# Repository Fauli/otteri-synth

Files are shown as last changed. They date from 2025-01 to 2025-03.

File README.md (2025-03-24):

# Otteri-synth

<p align="center">
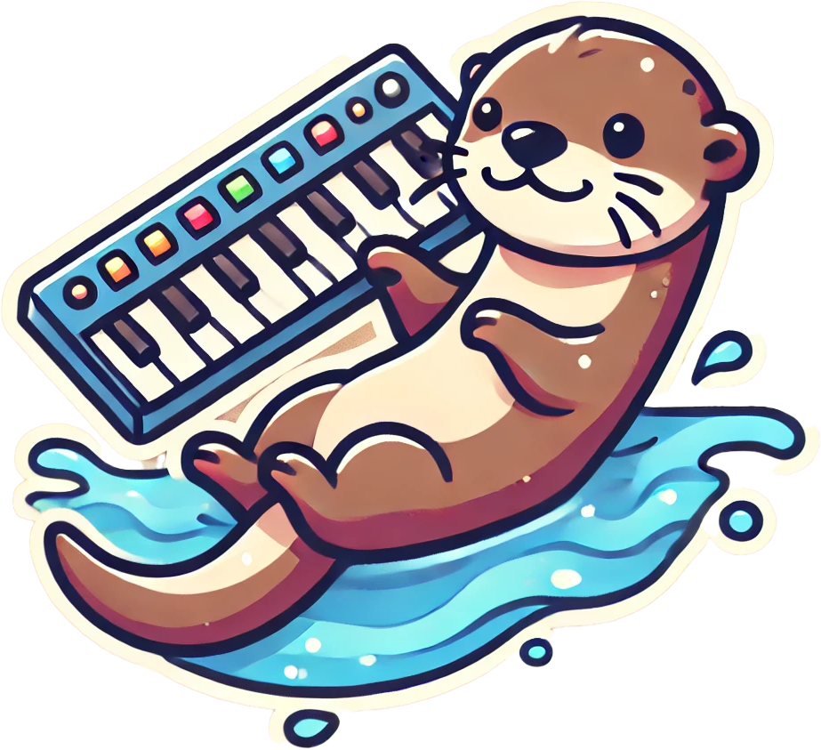
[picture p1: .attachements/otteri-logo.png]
Otteri DALL-E Image
    
    <br/>
    Cause otters like to play!
</p>

## Table of Contents

- [Otteri-synth](#otteri-synth)
  - [Table of Contents](#table-of-contents)
- [Introduction](#introduction)
- [Design](#design)
- [Hardware](#hardware)
  - [Parts List](#parts-list)
  - [Case](#case)
  - [Microcontroller](#microcontroller)
  - [Amplifier \& speakers](#amplifier--speakers)
  - [Power management](#power-management)
  - [Wiring diagram](#wiring-diagram)
  - [Final print config](#final-print-config)
  - [Putting it all together](#putting-it-all-together)
    - [KiCad](#kicad)
  - [Importing Teensy into KiCad](#importing-teensy-into-kicad)
  - [Schematics and PCB design](#schematics-and-pcb-design)
  - [Implementation using Perf Board](#implementation-using-perf-board)
  - [Ground loop](#ground-loop)
  - [Finished product](#finished-product)
    - [Final Project Files](#final-project-files)
- [Software](#software)
- [Demo](#demo)
- [Personal conclusion \& learnings](#personal-conclusion--learnings)

# Introduction
For fun I wanted to create a synthesizer that looks like an otter. It should be my daughters first synth :)

In these modern times I wanted to leverage what new tools have been available to design this project. In my mind I had a clear vision how the synth should look and play. I never did such a project before, so it was also a learning experience for me.

# Design
As the base I generated an image using [DALL-E](https://openai.com/index/dall-e-2/) and fed it into [TRELLIS](https://huggingface.co/JeffreyXiang/TRELLIS-image-large).

The prompt was:
```bash
Create a prototype of a synthesizer case.
White background, it is important that there is no background at all in the image. Should be childrens style, cool design and possible to 3d print on a 3d printer. I want to actually implement the case and use it for a synth project.
The synth should somewhat look like an otter.

# after some back and forth with some prototypes that had too many hands :P
There are too many hands, start over with an otter design, surprise me with a new and cool idea
```

In the end I was able to create an image in DALL-E that exactly matched what I had in mind.

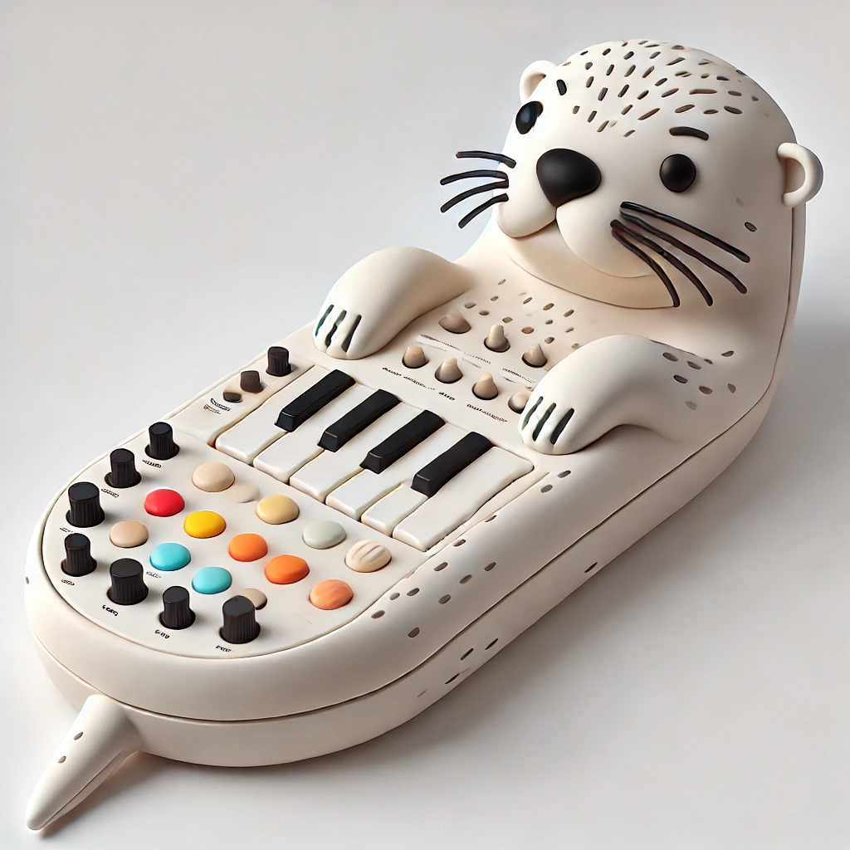
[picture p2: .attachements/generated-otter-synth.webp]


TRELLIS created an amazing mesh out of it that I could directly use as a starting point in [Blender](https://www.blender.org/).
You can find and download the mesh [here](.attachements/otteri-synth-generated.glb).

I then adapted the generated mesh to my liking and needs.

# Hardware

Because I have a 3d printer, the case and inner works was specially made for this synth.

## Parts List

Here is a quick overview of the used parts. A detailed description can be found below.

| Part | Amount | Description |
| --- | --- | --- |
| 3D Printed Case | 1 | Custom case to house all components |
| Teensy 3.2 | 1 | Microcontroller for handling audio processing |
| Teensy Audio Shield | 1 | Audio processing shield for Teensy |
| Adafruit MAX7944 | 1 | Amplifier for driving the speakers |
| 4Ohm 5W 40mm Speakers | 2 | Small speakers for audio output |
| Arcade Buttons | 10 | Durable buttons for user interaction |
| DC-015 circular power plug | 1 | Power plug for the synth |
| M5Stack Buck Converter 5 V | 1 | 12V to 5V converter for Teensy power |
| Ground Loop isolator | 1 | Prevent hum sound in speaker |
| Various Wires | - | Wiring for connecting all components |

## Case

The initial prototype was small, but after confirming its success, I scaled up the design to accommodate robust electronics suitable for a child's enthusiastic use. 

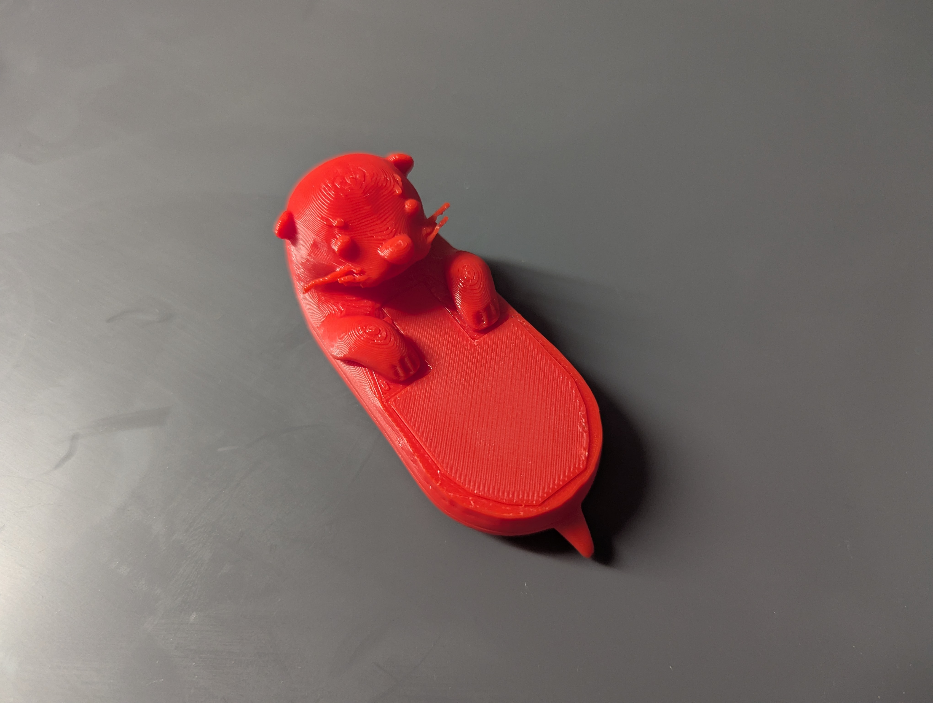
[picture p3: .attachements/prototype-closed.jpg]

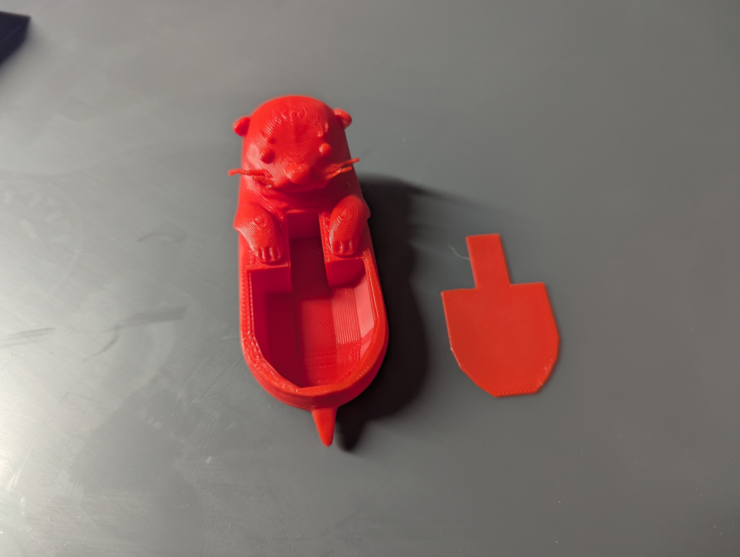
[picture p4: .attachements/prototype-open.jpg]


I opted for durable arcade buttons to withstand frequent interaction.

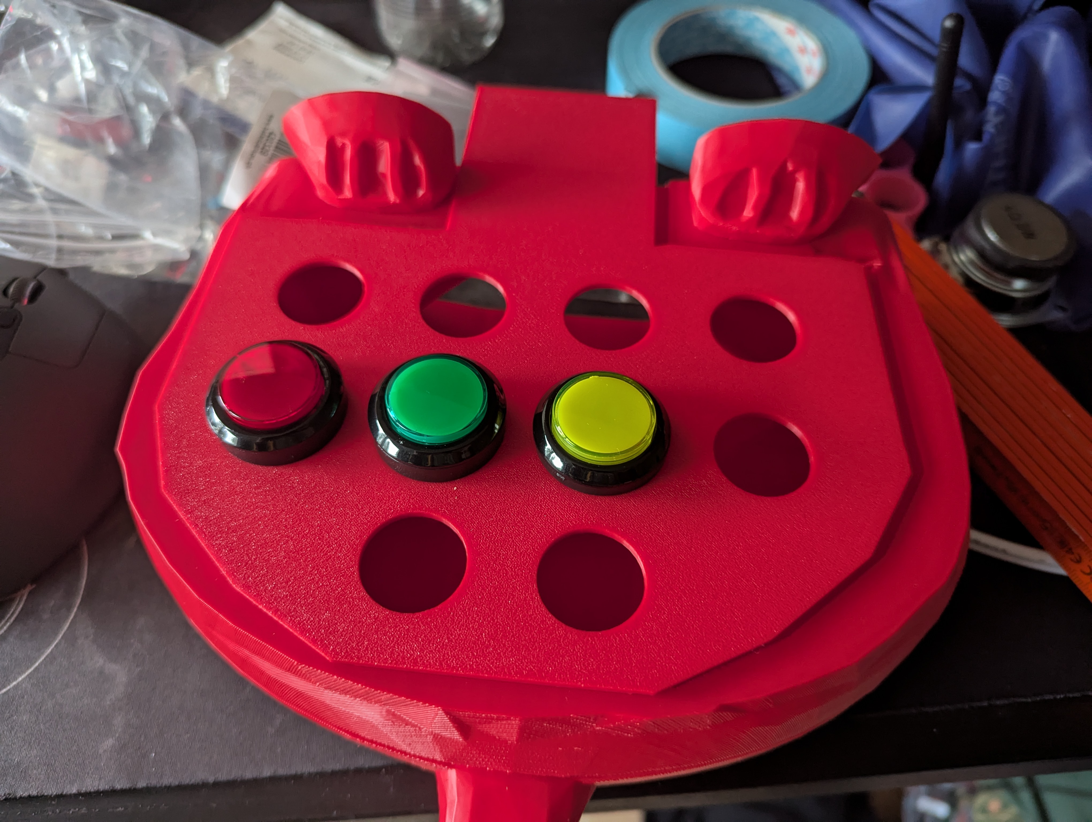
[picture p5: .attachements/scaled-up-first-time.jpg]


## Microcontroller

The core of the Otteri-synth is powered by a [Teensy 3.2](https://www.pjrc.com/store/teensy32.html) with the [Teensy Audio Shield](https://www.pjrc.com/store/teensy3_audio.html) as I still had them laying around at home.

The Teensy is excellent for synthesizer projects due to its high-performance ARM Cortex-M4 processor and real-time audio processing capabilities,

I'm a big fan of the teensy boards!

## Amplifier & speakers

Another component I still had laying around at home was an [Adafruit MAX7944](https://www.adafruit.com/product/1752) amplifier. For the speakers size, this will be more then enough.

As speakers I'm using 2 4Ohm 3W 40mm. They might be a little small, but should do the job.

## Power management

Teensy supports 5V power input, the amplifier needs 12V. In order to now have 2 inputs for power, I'm using a [Buck Converter - U125 - ME3116AM6G Step-Down Voltage Converter Unit, 5V, 1A](https://www.distrelec.ch/en/me3116am6g-step-down-voltage-converter-unit-5v-1a-m5stack-u125/p/30230761) to have the 12V shared input stepped down to 5V for the teensy:

```

          +---------------+
          |  12V Supply   |
          +---------------+
                |   |
                |   | 
         +------+   +------+  
         |                 |
  [Buck Converter]         |  
         |                 |
      5V Output        12V Output
         |                 |
   +-----+----+      +-----+-----+
   |  Teensy  |      | Amplifier |
   |   3.2    |      | (MAX9744) |
   +----------+      +-----------+
         |                 |
         +-- Common Ground --------+
```

To be able to re-use standard 12V power adapters, I prepared a hole at the back of the synth and added a circular power plug.

## Wiring diagram

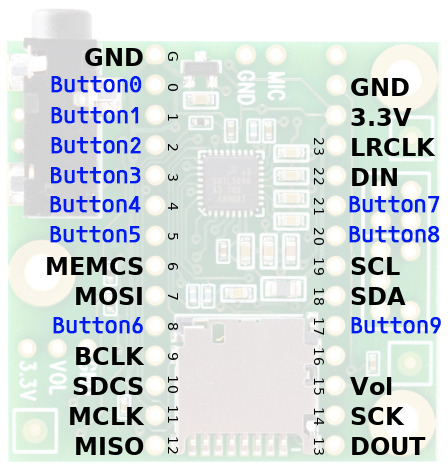
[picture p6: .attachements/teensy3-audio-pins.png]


| Button | Pin | Description |
| --- | --- | --- |
| Button 0 | 0 | Play note C |
| Button 1 | 1 | Play note D |
| Button 2 | 2 | Play note E |
| Button 3 | 3 | Play note F |
| Button 4 | 4 | Play note G |
| Button 5 | 5 | Play note A |
| Button 6 | 8 | Play note B |
| Button 7 | 21  | Play note C |
| Button 8 | 20  | Change preset (instrument) + volume |
| Button 9 | 17  | Change octave + volume |

*Additional note:* I added the functionality to change the volume by holding down Button 8 and Button 9 simultaneously and then changing the volume down or up with Button 0 and Button 1.

## Final print config

The first half I printed had way too small dowels. So they ended up breaking when being inserted into the body. 

So in try 2, I cut the Otter in Bambu Studio, using hexagons dowels with length 2cm and 1.5cm diameter as connectors. Initially I had a small gap between the two pieces. So I manually reduced the length of the dowels and re-printed just these.

**TODO: Add 3mf file of project...**

## Putting it all together

A first circuit prototype was made with a breadboard and some initial buttons I had still at home. The order for the remaining buttons was on it's way.

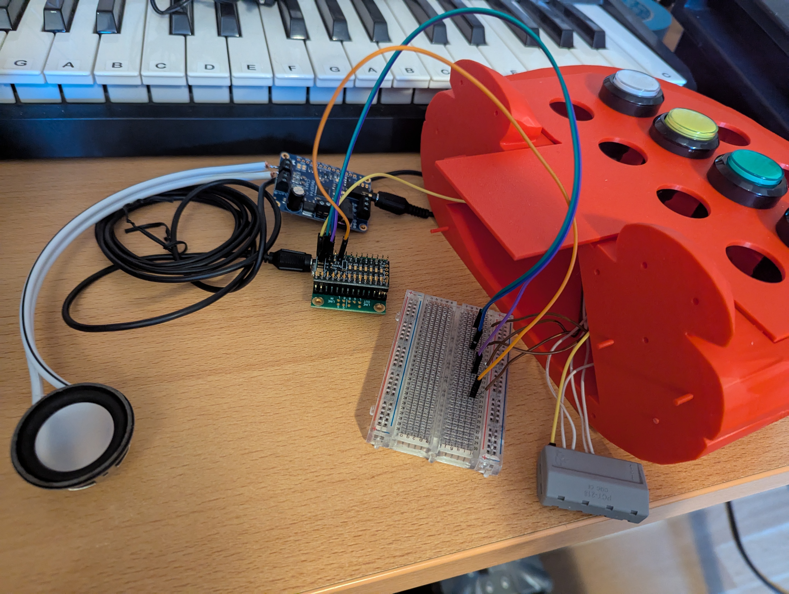
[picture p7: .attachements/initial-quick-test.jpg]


To fix the plate with the buttons to the body of the synth, I got melt threads in M3 size, like these:
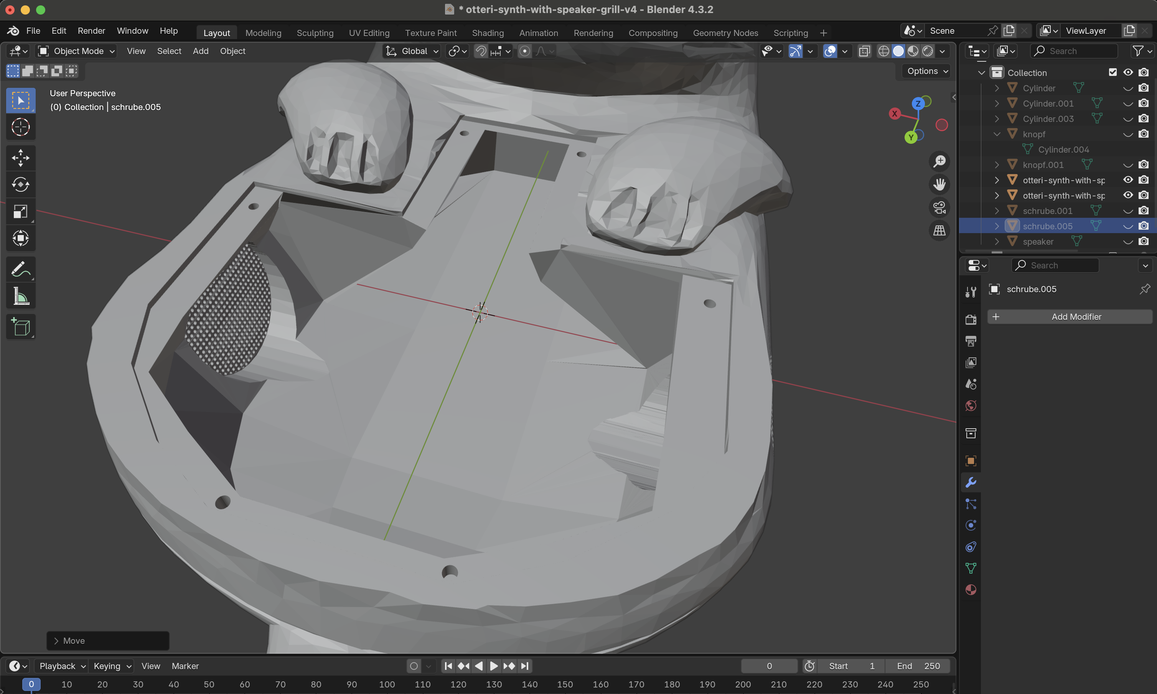
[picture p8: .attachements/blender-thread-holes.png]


In Blender I prepared the matching 4mm holes to fix the threads in.
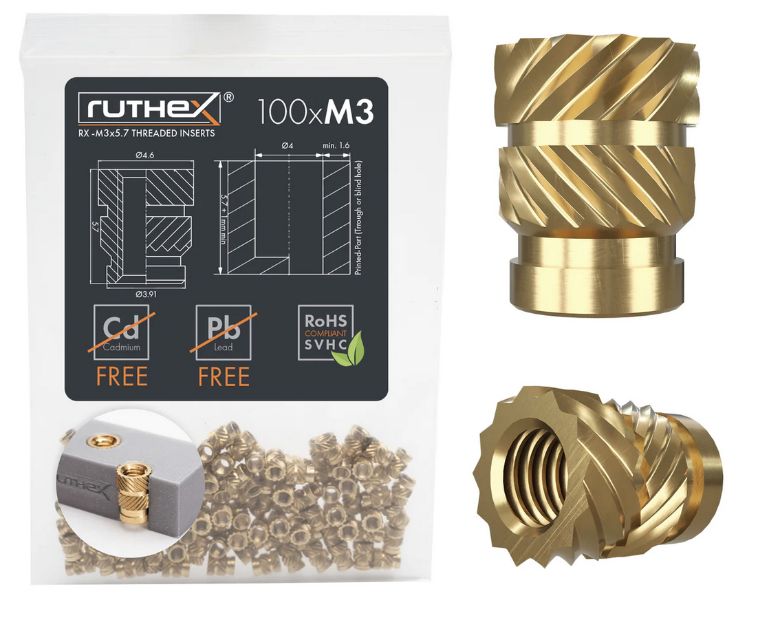
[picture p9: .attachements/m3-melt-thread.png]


The first full print was a success (even if the filament ran out and I had to switch to a different color to finish the print). I was able to verify my design and continue with the final hardware steps.

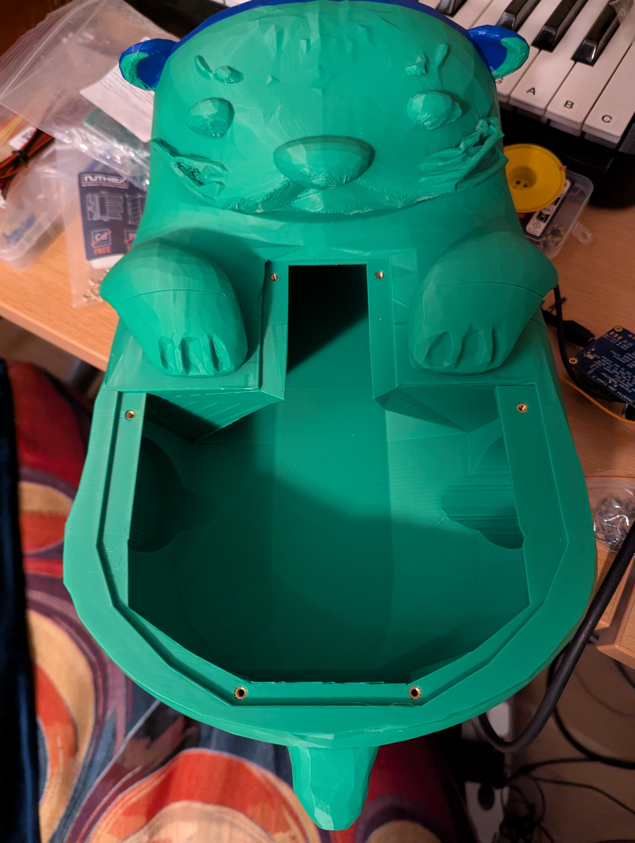
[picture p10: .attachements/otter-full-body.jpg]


I had to change the speaker because my initial one sounded very bad. The new one had holes on the side to proper fix the speaker to the case.

Otteri DALL-E Image

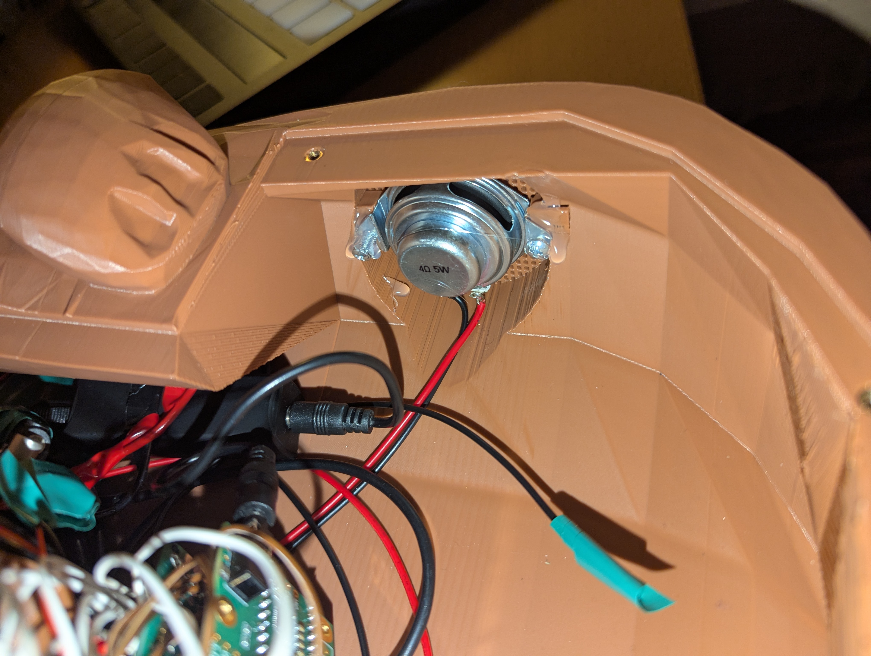
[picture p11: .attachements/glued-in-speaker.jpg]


### KiCad

Initially I had the idea to create and print a custom PDB for this project.
But after designing it and realizing the simplicity, I went with a prefboard setup.

Nevertheless, I went through the steps of creating the project and gerber files for the synth in Kicad as a learning excercise.
I started with importing the footpint into KiCad, arranging the schematics and drawing the PCB.

## Importing Teensy into KiCad
Download Teensy files from:
* [Teensy Library](https://github.com/XenGi/teensy_library)
* [Teensy.Pretty](https://github.com/XenGi/teensy.pretty)

And add them following these steps:

1. Open the Footprint Editor: From the main window in KiCad, navigate to Tools > Footprint Editor.
2. Manage Footprint Libraries (Symbol in the opened window):
    1. Within the Footprint Editor, go to Preferences > Manage Footprint Libraries....
    You’ll see two tabs: "Global Libraries" (libraries available to all projects) and "Project Specific Libraries" (libraries only available to the current project).
    2. To add a new library, click the “+” button under the appropriate tab.
    Point the file browser to the directory containing your .kicad_mod files. Select this directory as your library directory and provide a nickname for easy reference.
    3. Confirm your addition by clicking "OK".

Step 2: Manage Symbol Libraries

1. Access the Library Management:
    In the Symbol Editor, go to Preferences > Manage Symbol Libraries....
    This opens the Symbol Libraries Manager where you can add, remove, or modify symbol libraries.

1. Add a New Library:
    1. Click on the "Project Specific Libraries" tab to add the library only to your current project, or choose the "Global Libraries" tab to add the library to all KiCad projects on your system.
    1. Click the ‘+’ button at the bottom of the window to add a new library entry.

1. Specify Library Details:
    1. Nickname: Enter a nickname for the library. This nickname will be used to reference the library within KiCad.
    1. Library Path: Click on the folder icon next to the ‘Library Path’ field to browse to the location where you extracted your .lib file. Select the .lib file.
    1. Plugin Type: Ensure the plugin type is set to ‘Legacy’ for .lib files.
    The .dcm file, if located in the same directory, will automatically be linked for documentation purposes, so there's no need to do anything extra for it.

1. Confirm and Close:
    1. After entering all details, click “OK” to add the library.
    1. Close the Library Manager by clicking "OK" again.

## Schematics and PCB design

The schematics is created according the planned out pin setup above.

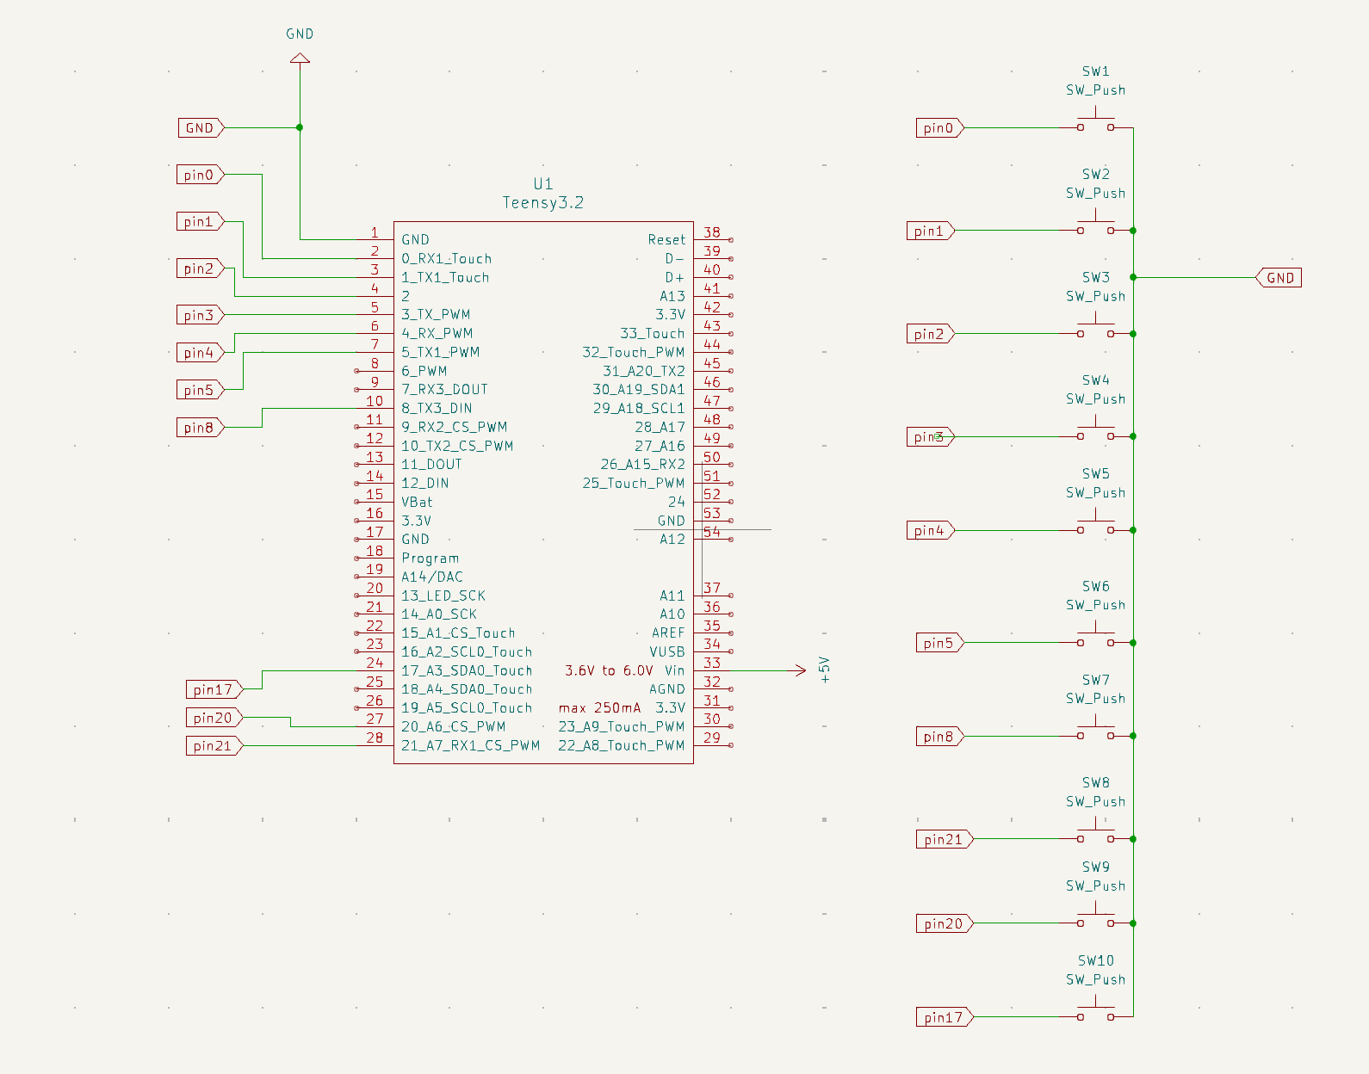
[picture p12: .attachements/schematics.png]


Out of the schematics, I was able to create an initial, simple PCB design.

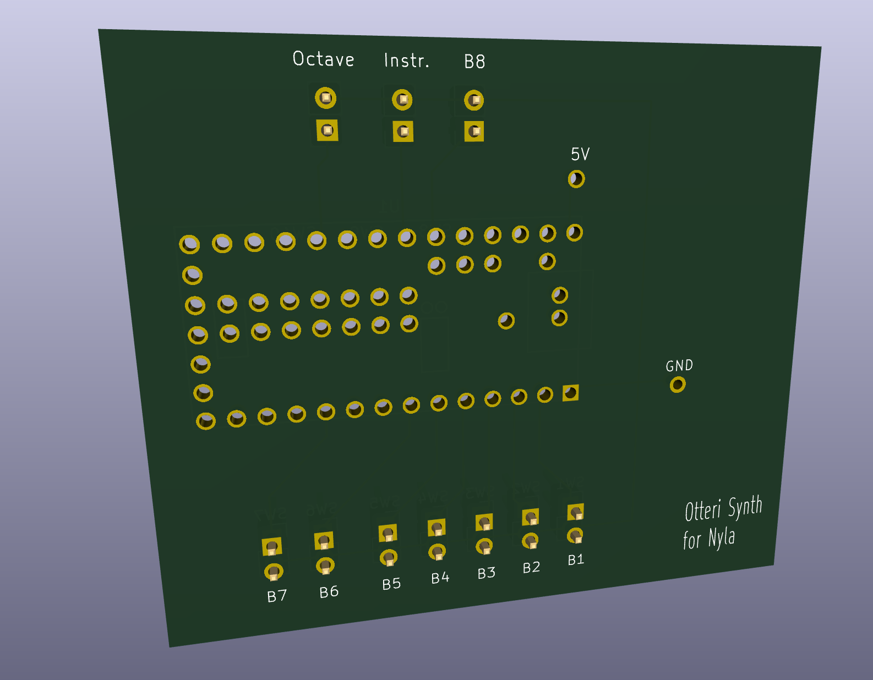
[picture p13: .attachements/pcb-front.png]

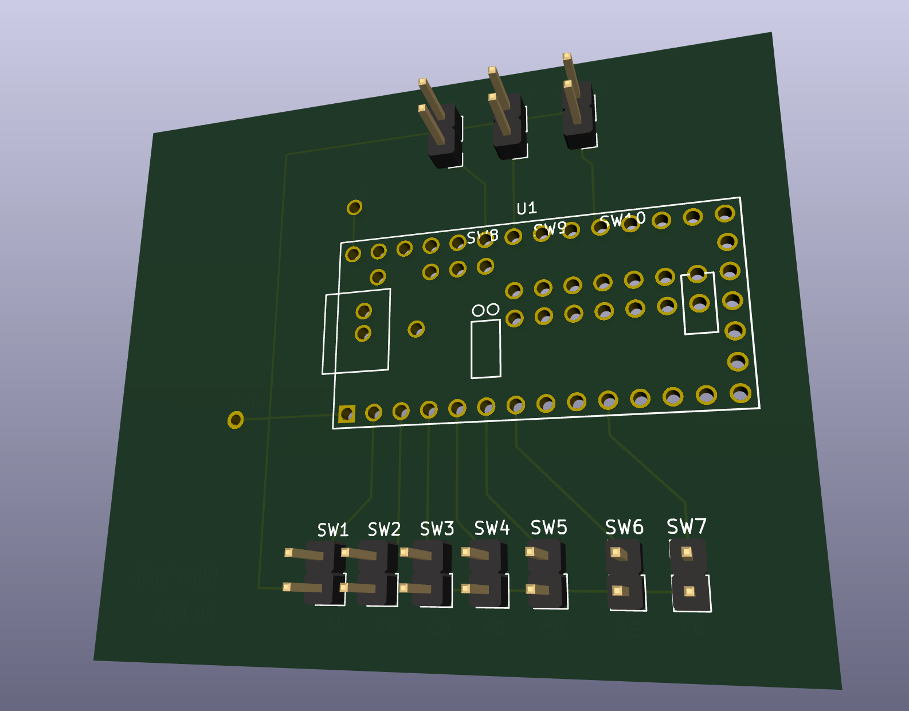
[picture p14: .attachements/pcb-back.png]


The files can be downloaded here:
* [Schematics](.attachements/otteri-synth.kicad_sch)
* [PCB Design](.attachements/otteri-synth.kicad_pcb)

## Implementation using Perf Board

Because the board was so simple, I ended up using a perf board and did the manual path setup using solder. 

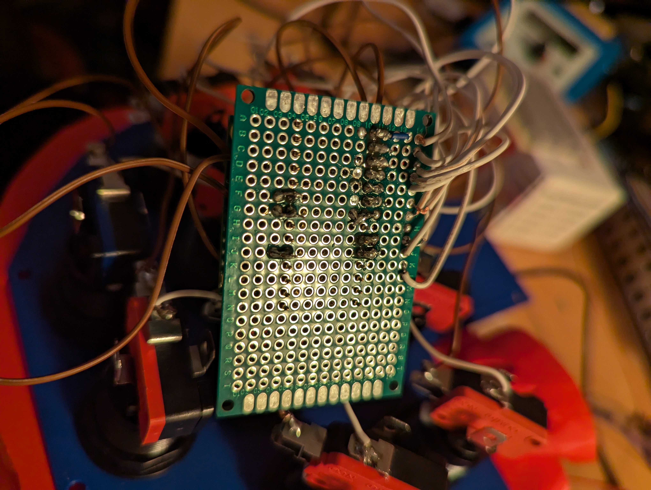
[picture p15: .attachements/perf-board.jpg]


It does not look very nice, but works well and is sturdy.

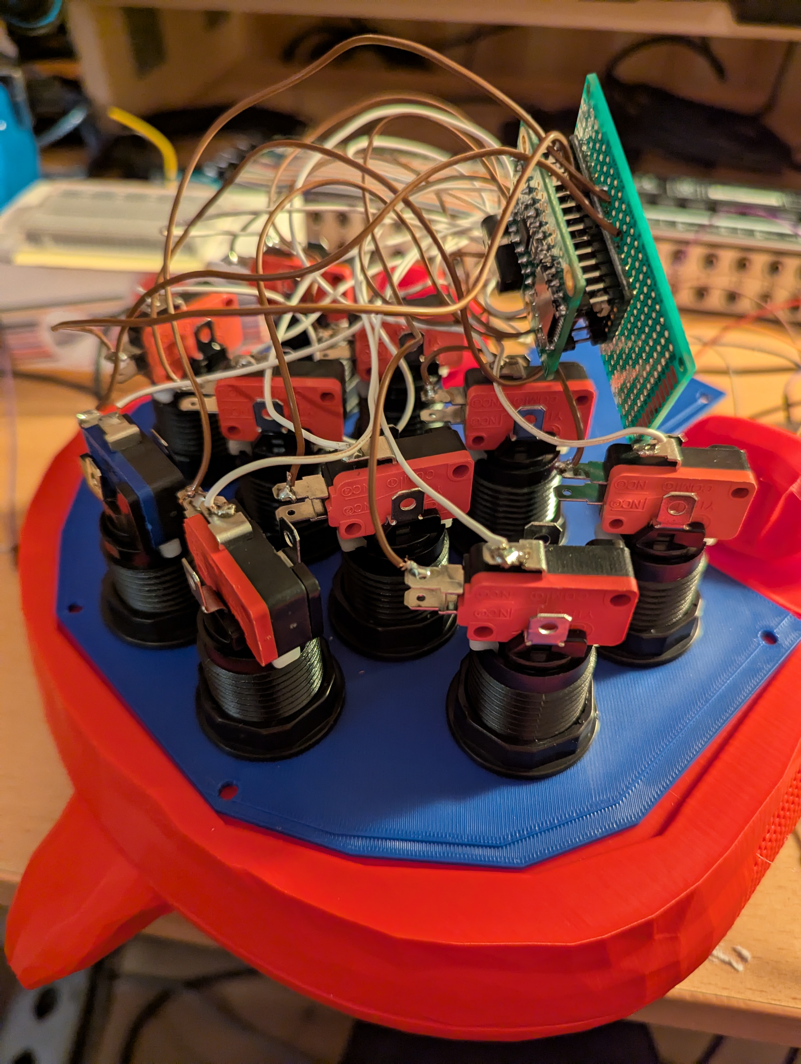
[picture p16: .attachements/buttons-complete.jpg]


Completed plate setup with all buttons attached.

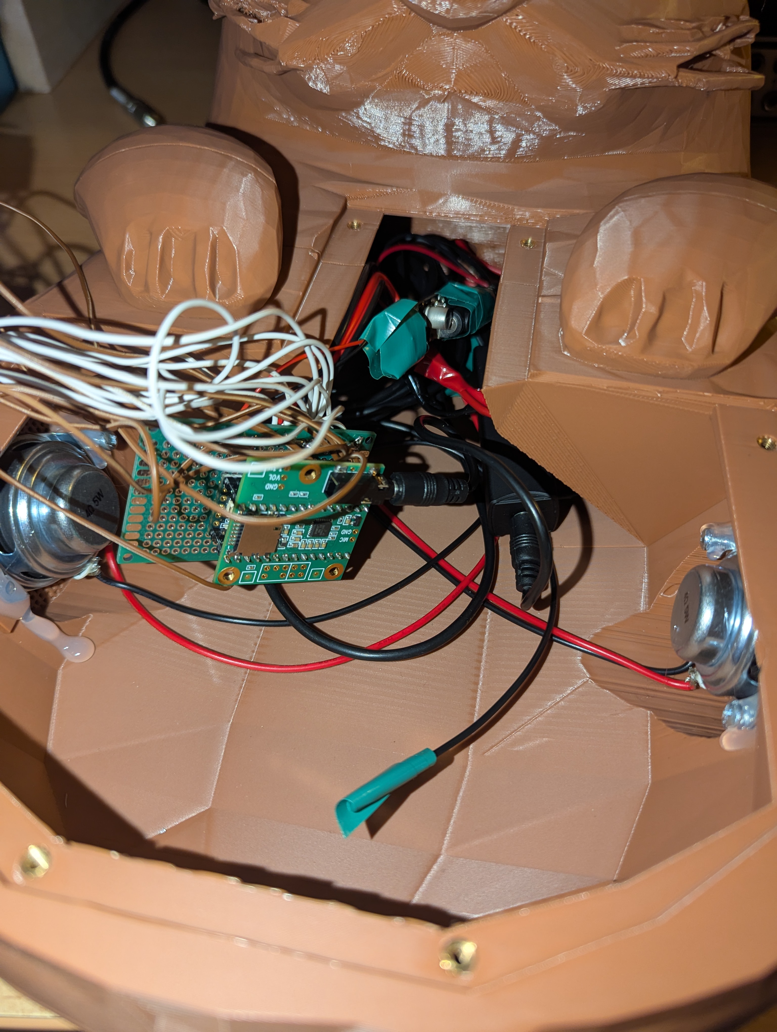
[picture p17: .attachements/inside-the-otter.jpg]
Otter in the otter


Inside of the finished otter.

## Ground loop

After I connected the setup and switched the power supply of the teensy from USB to the stepped down 5V VIN, i had a constant hum on the speakers.

This is called a ground loop. A ground loop occurs when multiple devices share more than one path to ground, creating an unintended loop.

In my case this was the commong ground of the power as well as the audio jack cable.

Top combat this I used a ground loop isolator. This fixed the problem.

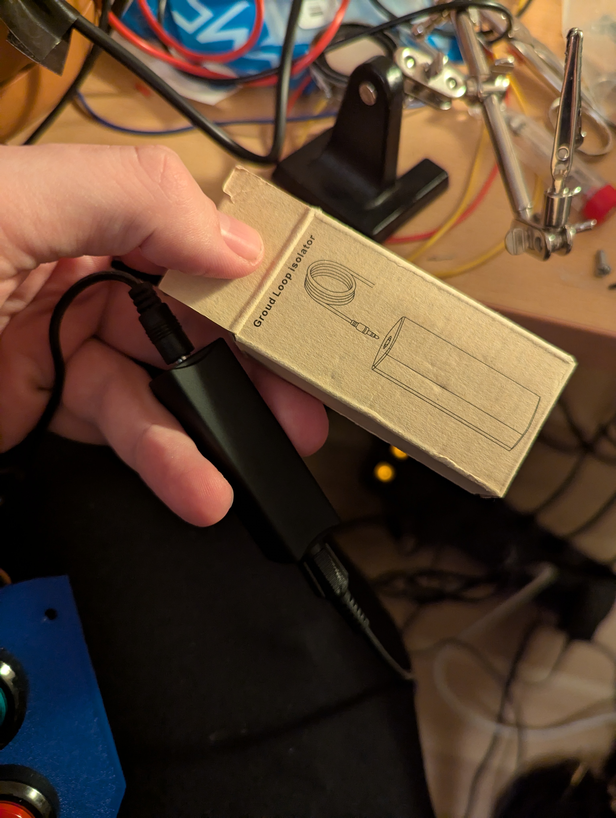
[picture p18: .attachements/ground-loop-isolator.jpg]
Ground Loop Isolator


## Finished product

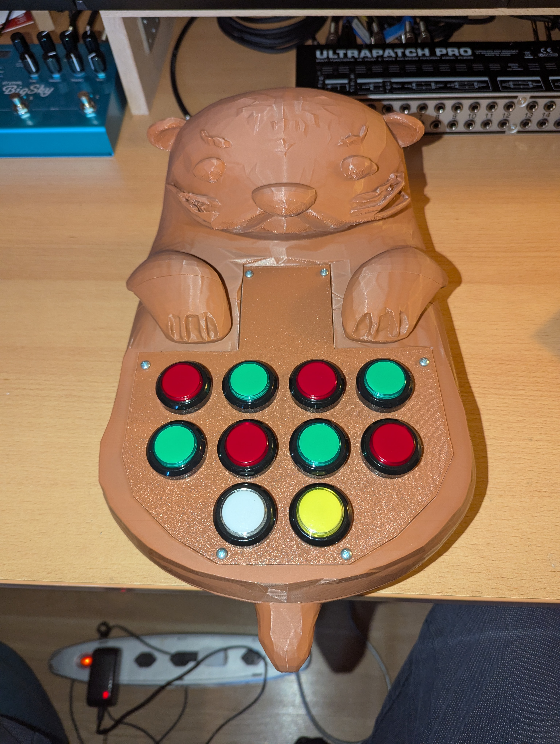
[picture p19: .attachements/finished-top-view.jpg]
Finished Top View


Top view of the synth.

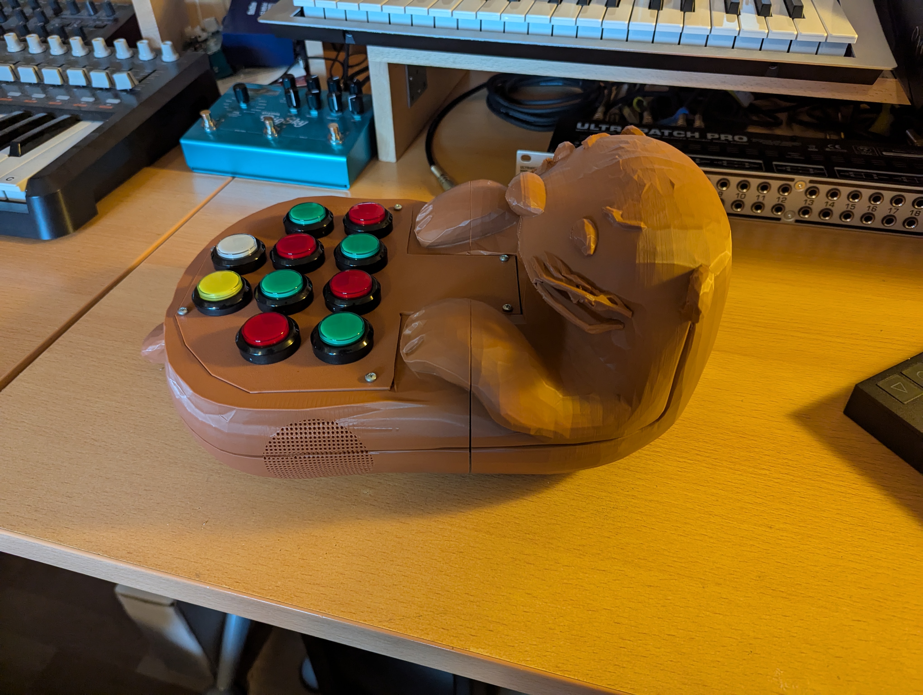
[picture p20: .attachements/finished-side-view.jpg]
Finished Side View


Side view of the synth.

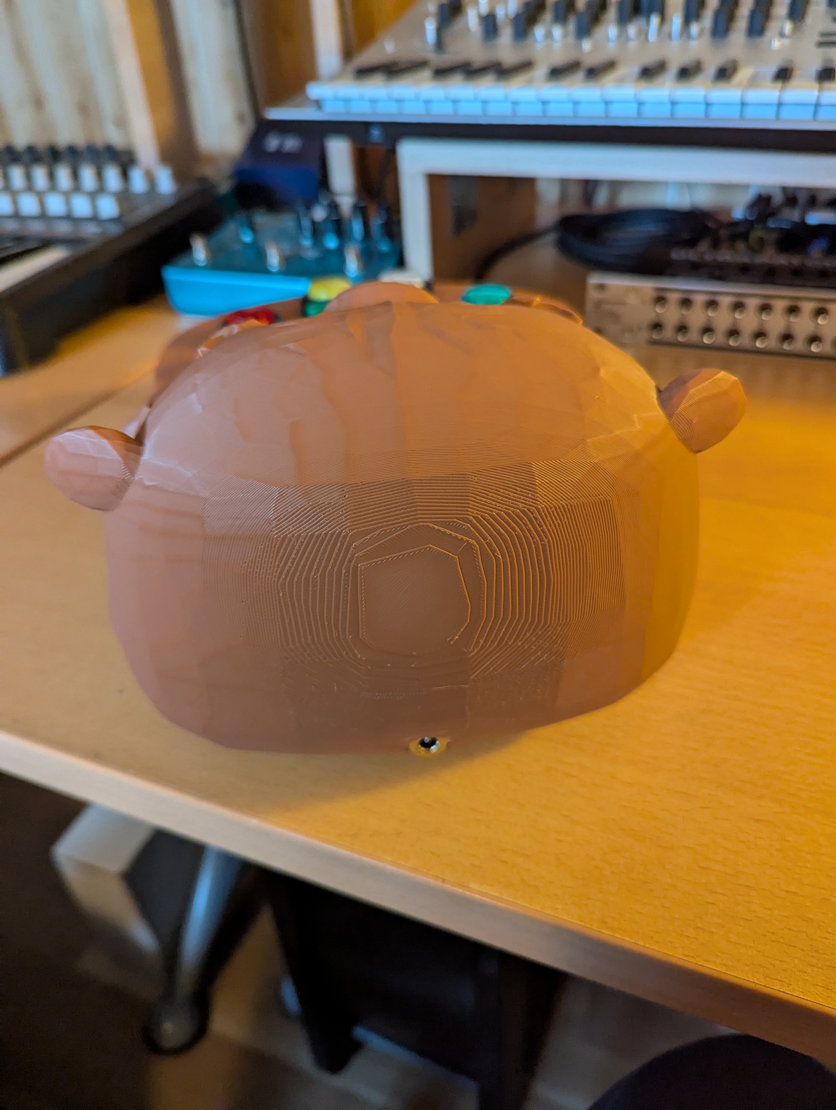
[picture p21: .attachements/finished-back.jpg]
Finished Back View


Back view of the synth, with the power plug.

### Final Project Files

You can find the [blender project](.attachements/otteri-synth-v6.blend) and the [3d STL file](.attachements/otteri-synth-v6.stl) in in the repo.

# Software

The project began with basic sketches in the Arduino IDE, but as the software evolved, I transitioned to [PlatformIO](https://platformio.org/) for enhanced code management and scalability.

The complete codebase is available in the `otteri-synth-code` directory.

I wanted to have multiple voices, in order to be able to not only play 1 key at a time. This was done by mutiplying the whole virtual audio setup 3 times and defining a common output to i2s.

I'm making heavy use of the [Teensy Audio Library](https://www.pjrc.com/teensy/td_libs_Audio.html) library.

# Demo

A demo of the sounds it makes before it got assambled: [Pre-assembly demo video](.attachements/first-demo.mov).

# Personal conclusion & learnings

This project was incredibly rewarding and enjoyable, serving not only as a creative outlet but also as a significant learning experience.

Throughout the process, I deepened my understanding of hardware integration, 3D printing nuances, and audio electronics.

Iterating through multiple prototypes highlighted the importance of adaptability, particularly when refining the 3D design and addressing unexpected technical challenges, such as the ground loop issue.

The synth turned out exactly as envisioned - playful, robust, and inviting to young hands eager to explore music. I'm excited to see how my daughter interacts with the Otteri-synth, and I'm hopeful it sparks a lasting curiosity and joy for music creation.

Future projects are already planned. Next time with more advanced controls and the Teensy 4.1 as controller.

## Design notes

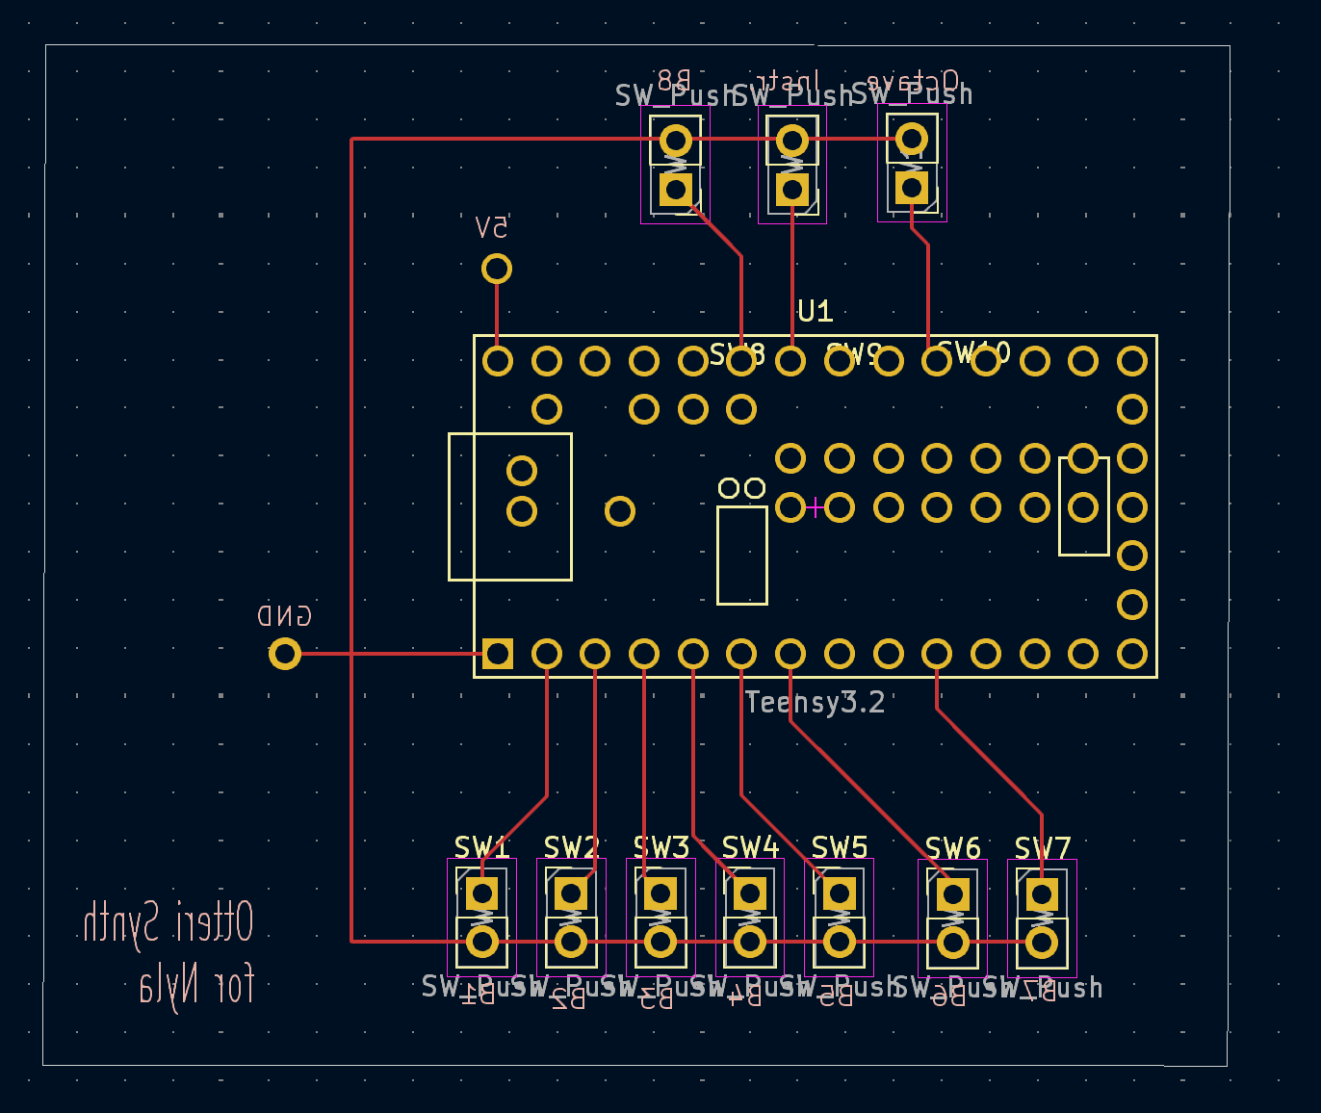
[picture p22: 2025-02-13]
.attachements/pcb-design.png

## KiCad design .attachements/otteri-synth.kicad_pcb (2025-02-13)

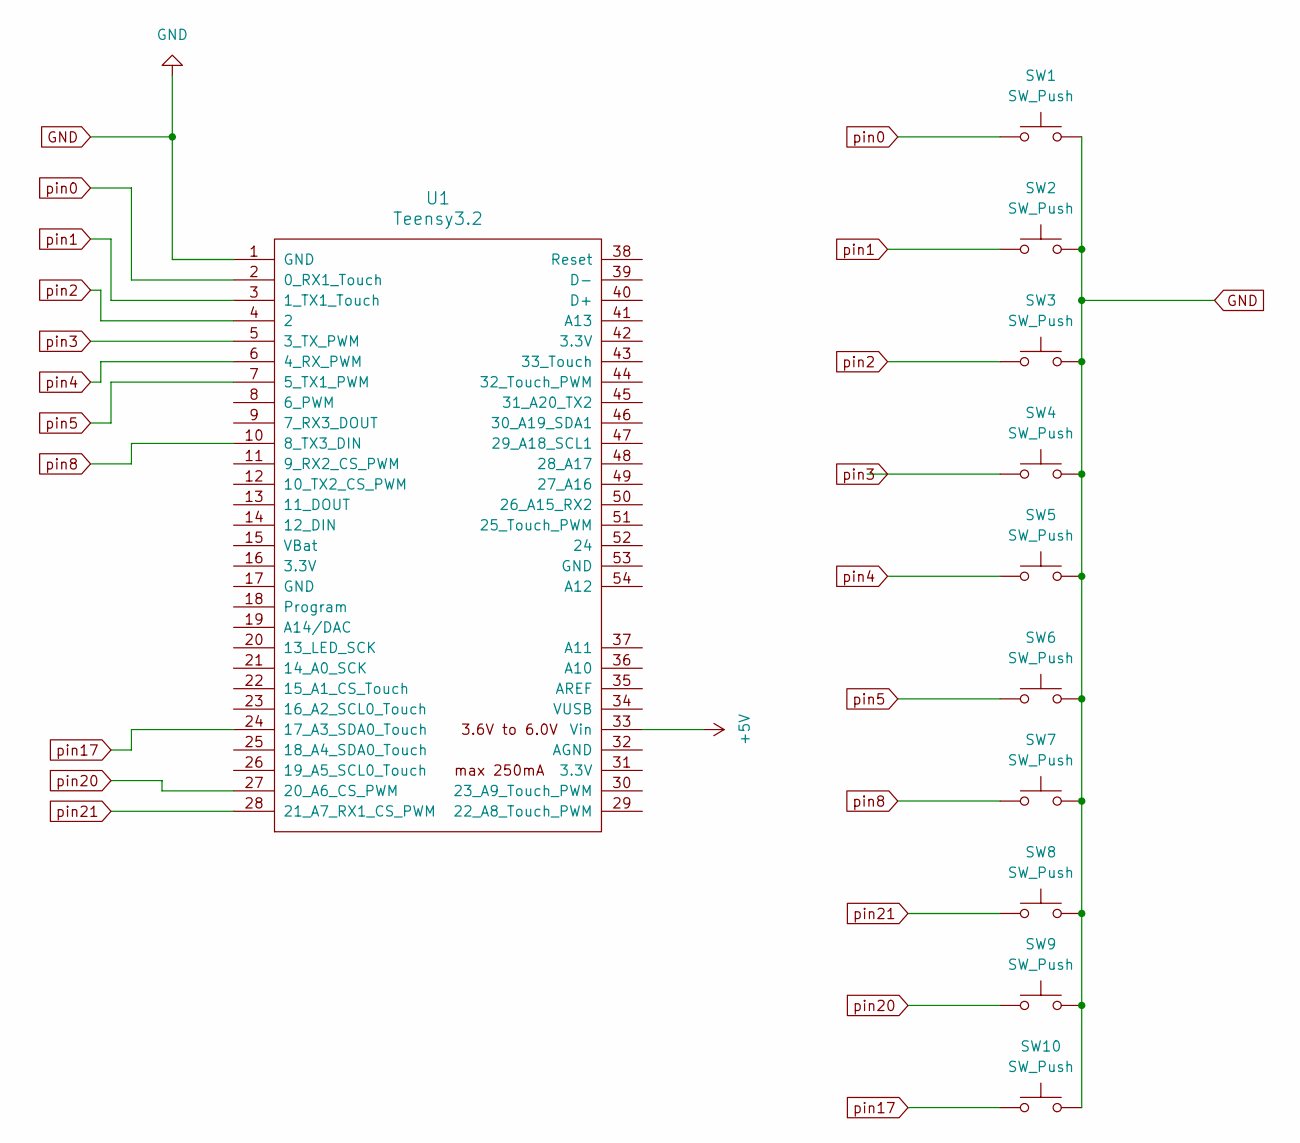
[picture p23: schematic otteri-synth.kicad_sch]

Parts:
SW1, SW2, SW3, SW4, SW5, SW6, SW7, SW8, SW9, SW10: SW_Push; PinHeader_1x02_P2.54mm_Vertical
U1: Teensy3.2; Teensy30_31_32_All_Pins

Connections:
+5V: U1.33 (Vin)
GND: SW1.2, SW2.2, SW3.2, SW4.2, SW5.2, SW6.2, SW7.2, SW8.2, SW9.2, SW10.2, U1.1 (GND)
pin0: SW1.1, U1.2 (0_RX1_Touch)
pin1: SW2.1, U1.3 (1_TX1_Touch)
pin2: SW3.1, U1.4 (2)
pin3: SW4.1, U1.5 (3_TX_PWM)
pin4: SW5.1, U1.6 (4_RX_PWM)
pin5: SW6.1, U1.7 (5_TX1_PWM)
pin8: SW7.1, U1.10 (8_TX3_DIN)
pin17: SW10.1, U1.24 (17_A3_SDA0_Touch)
pin20: SW9.1, U1.27 (20_A6_CS_PWM)
pin21: SW8.1, U1.28 (21_A7_RX1_CS_PWM)

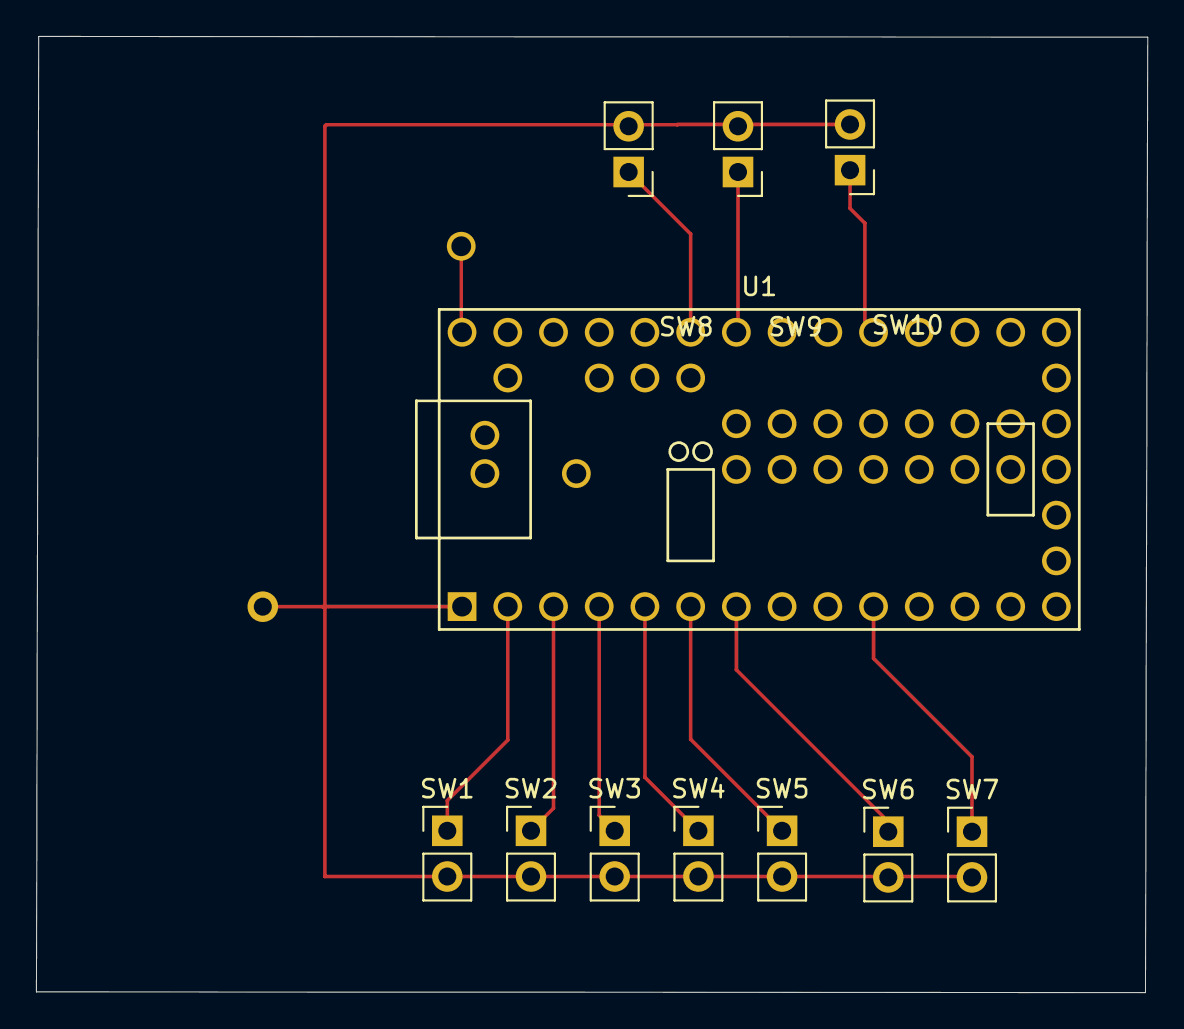
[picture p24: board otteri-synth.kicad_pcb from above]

Board: 2 copper layers, 61.7 x 53.1 mm, 11 parts (0 on the bottom side), 11 nets.

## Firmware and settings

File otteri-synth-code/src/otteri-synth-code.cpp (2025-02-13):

#include <Audio.h>
#include <Bounce2.h>
#include <math.h>

//------------------------------------------------------------------------------
// Forward Declarations
//------------------------------------------------------------------------------
void playNote(int noteIndex);
void stopNote(int noteIndex);

//------------------------------------------------------------------------------
// Helper Function: Compute Detuned Frequency
//------------------------------------------------------------------------------
/**
 * @brief Computes a detuned frequency from a base frequency.
 *
 * Uses preset-specific random detune and vibrato values.
 *
 * @param baseFreq       The base frequency in Hz.
 * @param fixedDetune    The fixed per-oscillator offset (in cents).
 * @param presetDetune   The preset-specified offset (in cents).
 * @param randomDepth    Maximum random detune depth (in cents).
 * @param vibDepth       Vibrato depth (in cents).
 * @param vibFrequency   Vibrato frequency (Hz).
 * @return The computed frequency in Hz.
 */
double computeDetunedFrequency(double baseFreq, int fixedDetune, int presetDetune,
                               double randomDepth, double vibDepth, double vibFrequency) {
  // Generate a fractional random detune between -randomDepth and +randomDepth cents.
  double randomDetune = random(-1000 * randomDepth, 1000 * randomDepth + 1) / 1000.0;
  
  // Vibrato component using current time.
  double vibrato = vibDepth * sin((millis() / 1000.0) * 2 * PI * vibFrequency);
  
  double totalDetune = fixedDetune + presetDetune + randomDetune + vibrato;
  return baseFreq * pow(2.0, totalDetune / 1200.0);
}

//------------------------------------------------------------------------------
// Global Constants and Structures
//------------------------------------------------------------------------------
const int numVoices = 3;
const int numPresets = 12;

// Base fixed detune values (in cents) for each oscillator.
const int baseDetune[3] = { -1, 1, 2 };

/**
 * @brief Holds configuration settings for a preset, including waveform,
 * envelope, detuning, and vibrato parameters.
 */
struct Preset {
  const char* name;
  // Oscillator settings:
  uint8_t waveType[3];    // Waveform type for each oscillator.
  float amplitude[3];     // Amplitude for each oscillator.
  
  // Envelope parameters (in milliseconds):
  unsigned int delay;
  unsigned int attack;
  unsigned int hold;
  unsigned int decay;
  float sustain;
  unsigned int release;
  
  // Preset-specific detune offsets (in cents) for each oscillator.
  int detune[3];
  
  // New parameters for detuning:
  double randomDetuneDepth; // Maximum random detune (cents).
  double vibratoDepth;      // Vibrato depth (cents).
  double vibratoFrequency;  // Vibrato frequency (Hz).
  
  // Optional pulse width settings for each oscillator (-1 if unused)
  float pulseWidth[3];
};

//------------------------------------------------------------------------------
// Preset Definitions (Each with Unique Detune/Vibrato Settings)
//------------------------------------------------------------------------------
Preset presets[numPresets] = {
  // Preset 0: Cosmic Bell
  { "Cosmic Bell",
    { WAVEFORM_SINE, WAVEFORM_SINE, WAVEFORM_SINE },
    { 0.8, 0.3, 0.2 },
    0, 50, 0, 500, 0.2, 1000,
    { 0, 0, 0 },
    1.0,   // randomDetuneDepth: ±1.0 cent
    0.5,   // vibratoDepth: 0.5 cents
    0.5,   // vibratoFrequency: 0.5 Hz
    { -1, -1, -1 }
  },
  // Preset 1: Vibrant Pad
  { "Vibrant Pad",
    { WAVEFORM_SAWTOOTH, WAVEFORM_TRIANGLE, WAVEFORM_SINE },
    { 0.8, 0.6, 0.4 },
    0, 800, 0, 1500, 0.7, 2500,
    { -5, 5, 0 },
    2.0,   // ±2.0 cents random detune
    0.7,   // 0.7 cents vibrato depth
    0.3,   // 0.3 Hz vibrato frequency
    { -1, -1, -1 }
  },
  // Preset 2: Aggressive Bass
  { "Aggressive Bass",
    { WAVEFORM_SQUARE, WAVEFORM_SAWTOOTH, WAVEFORM_PULSE },
    { 1.0, 0.8, 0.6 },
    0, 5, 0, 200, 0.0, 100,
    { 0, 0, 0 },
    0.5,   // Very subtle random detune
    0.2,   // Minimal vibrato
    0.1,   // Slow vibrato frequency
    { -1, -1, 0.5 }
  },
  // Preset 3: Digital Drone
  { "Digital Drone",
    { WAVEFORM_SAWTOOTH_REVERSE, WAVEFORM_TRIANGLE, WAVEFORM_SINE },
    { 0.8, 0.7, 0.5 },
    0, 1000, 0, 2000, 0.9, 3000,
    { -3, 3, 0 },
    1.5,   // Moderate random detune
    1.0,   // Noticeable vibrato
    0.4,   // 0.4 Hz vibrato frequency
    { -1, -1, -1 }
  },
  // Preset 4: Glitchy FX
  { "Glitchy FX",
    { WAVEFORM_SAMPLE_HOLD, WAVEFORM_SAMPLE_HOLD, WAVEFORM_SQUARE },
    { 0.7, 0.7, 0.6 },
    0, 10, 20, 30, 0.0, 20,
    { 0, 0, 0 },
    3.0,   // Wide random detune for chaotic effect
    0.0,   // No vibrato
    0.0,   // --
    { -1, -1, -1 }
  },
  // Preset 5: Analog Lead
  { "Analog Lead",
    { WAVEFORM_SAWTOOTH, WAVEFORM_PULSE, WAVEFORM_TRIANGLE },
    { 0.9, 0.8, 0.7 },
    0, 50, 0, 400, 0.6, 500,
    { 2, -2, 0 },
    1.5,   // Moderate random detune
    0.8,   // Noticeable vibrato
    0.8,   // 0.8 Hz vibrato frequency
    { -1, 0.4, -1 }
  },
  // Preset 6: Ethereal Voices
  { "Ethereal Voices",
    { WAVEFORM_SINE, WAVEFORM_TRIANGLE, WAVEFORM_SAWTOOTH },
    { 0.7, 0.5, 0.3 },
    100, 1200, 500, 800, 0.6, 1500,
    { 0, 0, 0 },
    1.0,   // Subtle random detune
    0.6,   // Smooth vibrato
    0.5,   // 0.5 Hz vibrato frequency
    { -1, -1, -1 }
  },
  // Preset 7: Crystal Organ
  { "Crystal Organ",
    { WAVEFORM_SINE, WAVEFORM_SINE, WAVEFORM_TRIANGLE },
    { 0.8, 0.8, 0.6 },
    0, 200, 0, 300, 0.8, 600,
    { 0, 0, 0 },
    0.5,   // Minimal random detune
    0.2,   // Very subtle vibrato
    0.2,   // 0.2 Hz vibrato frequency
    { -1, -1, -1 }
  },
  // Preset 8: Electric Pluck
  { "Electric Pluck",
    { WAVEFORM_TRIANGLE, WAVEFORM_SQUARE, WAVEFORM_SINE },
    { 1.0, 0.5, 0.3 },
    0, 5, 10, 50, 0.0, 80,
    { 0, 0, 0 },
    0.2,   // Very subtle random detune
    0.1,   // Minimal vibrato
    1.0,   // Faster vibrato for pluckiness
    { -1, -1, -1 }
  },
  // Preset 9: Warm Rhodes
  { "Warm Rhodes",
    { WAVEFORM_SAWTOOTH, WAVEFORM_SAWTOOTH, WAVEFORM_TRIANGLE },
    { 0.8, 0.6, 0.5 },
    0, 100, 0, 500, 0.7, 800,
    { -3, 3, 0 },
    0.8,   // Moderate random detune
    0.5,   // Smooth vibrato
    0.4,   // 0.4 Hz vibrato frequency
    { -1, -1, -1 }
  },
  // Preset 10: Spacey Arp
  { "Spacey Arp",
    { WAVEFORM_TRIANGLE, WAVEFORM_SAWTOOTH, WAVEFORM_SINE },
    { 0.7, 0.7, 0.5 },
    0, 20, 0, 300, 0.5, 400,
    { 5, -5, 0 },
    1.2,   // Slightly wider random detune
    0.7,   // Moderate vibrato
    0.6,   // 0.6 Hz vibrato frequency
    { -1, -1, -1 }
  },
  // Preset 11: Experimental Noise
  { "Experimental Noise",
    { WAVEFORM_SAMPLE_HOLD, WAVEFORM_SINE, WAVEFORM_TRIANGLE },
    { 0.8, 0.5, 0.6 },
    0, 50, 0, 400, 0.3, 800,
    { 0, 0, 0 },
    2.0,   // Wide random detune for chaos
    1.0,   // Noticeable vibrato
    1.5,   // Faster vibrato frequency
    { -1, -1, -1 }
  }
};

// Global preset state
int currentPresetIndex = 0;
int currentPresetDetune[3] = { 0, 0, 0 };

//------------------------------------------------------------------------------
// Audio Objects and Patch Connections
//------------------------------------------------------------------------------
AudioSynthWaveform waveform1[numVoices];  // Oscillator 1
AudioSynthWaveform waveform2[numVoices];  // Oscillator 2
AudioSynthWaveform waveform3[numVoices];  // Oscillator 3
AudioMixer4 mixer1[numVoices];            // Mixer for each voice's oscillators
AudioEffectEnvelope envelope1[numVoices]; // Envelope for each voice

AudioMixer4 outputMixer;
AudioOutputI2S i2s1;                 // I2S output
AudioControlSGTL5000 sgtl5000_1;       // Audio control chip

// Patch cords for each voice:
AudioConnection patchCord1(waveform1[0], 0, mixer1[0], 0);
AudioConnection patchCord2(waveform2[0], 0, mixer1[0], 1);
AudioConnection patchCord3(waveform3[0], 0, mixer1[0], 2);
AudioConnection patchCord4(mixer1[0], envelope1[0]);
AudioConnection patchCord5(envelope1[0], 0, outputMixer, 0);

AudioConnection patchCord7(waveform1[1], 0, mixer1[1], 0);
AudioConnection patchCord8(waveform2[1], 0, mixer1[1], 1);
AudioConnection patchCord9(waveform3[1], 0, mixer1[1], 2);
AudioConnection patchCord10(mixer1[1], envelope1[1]);
AudioConnection patchCord11(envelope1[1], 0, outputMixer, 1);

AudioConnection patchCord13(waveform1[2], 0, mixer1[2], 0);
AudioConnection patchCord14(waveform2[2], 0, mixer1[2], 1);
AudioConnection patchCord15(waveform3[2], 0, mixer1[2], 2);
AudioConnection patchCord16(mixer1[2], envelope1[2]);
AudioConnection patchCord17(envelope1[2], 0, outputMixer, 2);

AudioConnection patchCord192(outputMixer, 0, i2s1, 0);
AudioConnection patchCord20(outputMixer, 0, i2s1, 1);

//------------------------------------------------------------------------------
// Button Setup
//------------------------------------------------------------------------------
// 10 buttons:
//  - Buttons 0-7 (pins 0,1,2,3,4,5,8,21): Note play.
//  - Button 8 (pin 20): Preset selection.
//  - Button 9 (pin 17): Octave cycling.
// When buttons 8 and 9 are held, note buttons 0 and 1 adjust volume.
const int numButtons = 10;
const int buttonPins[numButtons] = { 0, 1, 2, 3, 4, 5, 8, 21, 20, 17 };
Bounce buttons[numButtons];

//------------------------------------------------------------------------------
// Note Frequencies and Voice Management
//------------------------------------------------------------------------------
// Eight note frequencies for octave 5 (C5, D5, E5, F5, G5, A5, B5, C6).
float noteFrequencies[8] = { 523.25, 587.33, 659.25, 698.46, 783.99, 880.00, 987.77, 1046.50 };

/*
  voiceNoteIndices[] tracks which note (by index) is playing on each voice.
  A value of -1 indicates an inactive voice.
*/
int voiceNoteIndices[numVoices];
int currentVoice = 0; // Round-robin voice allocation

// Current octave (default 5). Frequencies scale by 2^(currentOctave - 5).
int currentOctave = 5;

//------------------------------------------------------------------------------
// Global Volume Control Variables
//------------------------------------------------------------------------------
float currentVolume = 0.65;  // Default volume (0.0 to 1.0)
bool volumeMode = false;     // Flag for volume mode

//------------------------------------------------------------------------------
// Preset and Voice Functions
//------------------------------------------------------------------------------
/**
 * @brief Loads a preset and applies its settings to all voices.
 */
void changeToPreset(int presetIndex) {
  if (presetIndex < 0 || presetIndex >= numPresets)
    return;
  
  Preset preset = presets[presetIndex];
  Serial.print("Changing preset to: ");
  Serial.println(preset.name);
  
  // Update global preset detune offsets.
  for (int i = 0; i < 3; i++) {
    currentPresetDetune[i] = preset.detune[i];
  }
  
  // Apply oscillator and envelope settings.
  for (int i = 0; i < numVoices; i++) {
    waveform1[i].begin(preset.waveType[0]);
    waveform1[i].amplitude(preset.amplitude[0]);
    
    waveform2[i].begin(preset.waveType[1]);
    waveform2[i].amplitude(preset.amplitude[1]);
    
    waveform3[i].begin(preset.waveType[2]);
    waveform3[i].amplitude(preset.amplitude[2]);
    
    if (preset.pulseWidth[0] >= 0)
      waveform1[i].pulseWidth(preset.pulseWidth[0]);
    if (preset.pulseWidth[1] >= 0)
      waveform2[i].pulseWidth(preset.pulseWidth[1]);
    if (preset.pulseWidth[2] >= 0)
      waveform3[i].pulseWidth(preset.pulseWidth[2]);
    
    envelope1[i].delay(preset.delay);
    envelope1[i].attack(preset.attack);
    envelope1[i].hold(preset.hold);
    envelope1[i].decay(preset.decay);
    envelope1[i].sustain(preset.sustain);
    envelope1[i].release(preset.release);
  }
}

/**
 * @brief Plays a note using round-robin voice allocation, applying octave and detuning.
 */
void playNote(int noteIndex) {
  stopNote(noteIndex);
  currentVoice = (currentVoice + 1) % numVoices;
  voiceNoteIndices[currentVoice] = noteIndex;
  
  double baseFreq = noteFrequencies[noteIndex] * pow(2, currentOctave - 5);
  
  // Get current preset detune parameters.
  double randomDepth = presets[currentPresetIndex].randomDetuneDepth;
  double vibDepth     = presets[currentPresetIndex].vibratoDepth;
  double vibFrequency = presets[currentPresetIndex].vibratoFrequency;
  
  waveform1[currentVoice].frequency(
    computeDetunedFrequency(baseFreq, baseDetune[0], currentPresetDetune[0],
                            randomDepth, vibDepth, vibFrequency)
  );
  waveform2[currentVoice].frequency(
    computeDetunedFrequency(baseFreq, baseDetune[1], currentPresetDetune[1],
                            randomDepth, vibDepth, vibFrequency)
  );
  waveform3[currentVoice].frequency(
    computeDetunedFrequency(baseFreq, baseDetune[2], currentPresetDetune[2],
                            randomDepth, vibDepth, vibFrequency)
  );
  
  envelope1[currentVoice].noteOn();
  
  Serial.print("Playing note ");
  Serial.print(baseFreq);
  Serial.print(" Hz on voice ");
  Serial.println(currentVoice);
}

/**
 * @brief Stops a note if it is currently playing.
 */
void stopNote(int noteIndex) {
  for (int i = 0; i < numVoices; i++) {
    if (voiceNoteIndices[i] == noteIndex) {
      envelope1[i].noteOff();
      voiceNoteIndices[i] = -1;
      Serial.print("Stopped note ");
      Serial.println(noteFrequencies[noteIndex]);
    }
  }
}

//------------------------------------------------------------------------------
// Setup and Main Loop
//------------------------------------------------------------------------------
void setup() {
  Serial.begin(9600);
  AudioMemory(15);
  
  sgtl5000_1.enable();
  sgtl5000_1.volume(currentVolume);
  
  for (int i = 0; i < numButtons; i++) {
    pinMode(buttonPins[i], INPUT_PULLUP);
    buttons[i].attach(buttonPins[i]);
    buttons[i].interval(5);
  }
  
  for (int i = 0; i < numVoices; i++) {
    voiceNoteIndices[i] = -1;
  }
  
  changeToPreset(currentPresetIndex);
  Serial.println("Setup complete.");
}

void loop() {
  for (int i = 0; i < numButtons; i++) {
    buttons[i].update();
  }
  
  // Check if preset (button 8) and octave (button 9) buttons are held.
  bool presetHeld = (buttons[8].read() == LOW);
  bool octaveHeld  = (buttons[9].read() == LOW);
  
  if (presetHeld && octaveHeld) {
    if (!volumeMode) {
      volumeMode = true;
      Serial.println("Volume mode activated.");
    }
    if (buttons[0].fell()) {
      currentVolume -= 0.05;
      if (currentVolume < 0.0) currentVolume = 0.0;
      sgtl5000_1.volume(currentVolume);
      Serial.print("Volume decreased to ");
      Serial.println(currentVolume);
    }
    if (buttons[1].fell()) {
      currentVolume += 0.05;
      if (currentVolume > 1.0) currentVolume = 1.0;
      sgtl5000_1.volume(currentVolume);
      Serial.print("Volume increased to ");
      Serial.println(currentVolume);
    }
  } else {
    if (volumeMode) {
      volumeMode = false;
      Serial.println("Exiting volume mode.");
    }
    for (int i = 0; i < 8; i++) {
      if (buttons[i].fell()) {
        Serial.print("Button on pin ");
        Serial.print(buttonPins[i]);
        Serial.println(" activated (note button).");
        playNote(i);
      }
      if (buttons[i].rose()) {
        Serial.print("Button on pin ");
        Serial.print(buttonPins[i]);
        Serial.println(" released (note button).");
        stopNote(i);
      }
    }
    if (buttons[8].fell()) {
      Serial.print("Button on pin ");
      Serial.print(buttonPins[8]);
      Serial.println(" activated (instrument selection).");
      currentPresetIndex = (currentPresetIndex + 1) % numPresets;
      changeToPreset(currentPresetIndex);
    }
    if (buttons[9].fell()) {
      Serial.print("Button on pin ");
      Serial.print(buttonPins[9]);
      Serial.println(" activated (octave cycle).");
      currentOctave++;
      if (currentOctave > 6) currentOctave = 3;
      Serial.print("Octave set to ");
      Serial.println(currentOctave);
    }
  }
}

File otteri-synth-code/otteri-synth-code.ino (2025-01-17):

#include <Bounce2.h>
#include <Audio.h>

// Define notes
#define NOTE_C4  261.63
#define NOTE_D4  293.66
#define NOTE_E4  329.63
#define NOTE_F4  349.23
#define NOTE_G4  392.00
#define NOTE_A4  440.00
#define NOTE_B4  493.88
#define NOTE_C5  523.25

// Audio library components
AudioSynthWaveform       waveform1;           // Waveform generator
AudioEffectEnvelope      envelope1;           // Envelope generator
AudioFilterStateVariable filter1;             // Filter to modify the waveform
AudioOutputI2S           i2s1;                // Audio output over I2S
AudioConnection          patchCord1(waveform1, envelope1);
AudioConnection          patchCord2(envelope1, 0, filter1, 0);
AudioConnection          patchCord3(envelope1, 0, i2s1, 0);
AudioConnection          patchCord4(envelope1, 0, i2s1, 1);
AudioControlSGTL5000     sgtl5000_1;          // Control chip for I2S

// Button setup
const int numButtons = 9;
Bounce buttons[numButtons] = {
  Bounce(0, 5), Bounce(1, 5), Bounce(2, 5), Bounce(3, 5),
  Bounce(4, 5), Bounce(5, 5), Bounce(6, 5), Bounce(7, 5),
  Bounce(8, 5)
};

float notes[numButtons - 1] = {NOTE_C4, NOTE_D4, NOTE_E4, NOTE_F4, NOTE_G4, NOTE_A4, NOTE_B4, NOTE_C5};
int currentPreset = 0;

void setup() {
  Serial.begin(9600);
  AudioMemory(15);
  sgtl5000_1.enable();
  sgtl5000_1.volume(0.6);
  
  // Initialize buttons
  for (int i = 0; i < numButtons; ++i) {
    pinMode(i, INPUT_PULLUP);
    buttons[i].attach(i);
    buttons[i].interval(5);
  }
  
  waveform1.begin(WAVEFORM_SINE);
  waveform1.amplitude(0.9);

  envelope1.attack(50);
  envelope1.decay(120);
  envelope1.sustain(0.7);
  envelope1.release(250);
  
  filter1.resonance(0.5); // Slightly resonant

  Serial.println("Setup complete. Default waveform: Sine.");
}

void loop() {
  for (int i = 0; i < numButtons - 1; ++i) {
    buttons[i].update();
    if (buttons[i].fell()) {
      waveform1.frequency(notes[i]);
      envelope1.noteOn();
      
      Serial.print("Note played: ");
      Serial.println(notes[i]);
    }
    if (buttons[i].rose()) {
      envelope1.noteOff();
      Serial.println("Note stopped.");
    }
  }
  
  // Check for preset change
  buttons[8].update();
  if (buttons[8].fell()) {
    currentPreset = (currentPreset + 1) % 5;
    Serial.print("Preset changed to: ");
    switch (currentPreset) {
      case 0: waveform1.begin(WAVEFORM_SINE); Serial.println("Sine"); break;
      case 1: waveform1.begin(WAVEFORM_SQUARE); Serial.println("Square"); break;
      case 2: waveform1.begin(WAVEFORM_SAWTOOTH); Serial.println("Sawtooth"); break;
      case 3: waveform1.begin(WAVEFORM_TRIANGLE); Serial.println("Triangle"); break;
      case 4: waveform1.begin(WAVEFORM_ARBITRARY); Serial.println("Arbitrary"); break;
    }
    // Make sure the filter frequency is set appropriately for the preset
    filter1.frequency(5000 - currentPreset * 1000);
  }
}

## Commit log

2025-01-18 buttons work
2025-02-13 add KiCad files
    [otteri-synth.kicad_pcb, otteri-synth.kicad_sch]
